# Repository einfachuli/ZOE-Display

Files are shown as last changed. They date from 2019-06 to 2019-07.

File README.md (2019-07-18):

# ZOE-Display

<pre>
!!!!!!!!!!!!!!!!!!!!!!!!!!!!!!!!!!!!!!!!!!!!!!!!!!!!!!!!!!!!!!!!!!
!!!! OHNE GEWÄHR, ALLES AUF EIGENE GEFAHR, NUR ZU TESTZWECKEN !!!!
!!!!!!!!!!!!!!!!!!!!!!!!!!!!!!!!!!!!!!!!!!!!!!!!!!!!!!!!!!!!!!!!!!
</pre>

## Verwendete Bauteile

- ESP32-Development-Board (z.B. https://www.ebay.de/itm/162572643462 oder https://www.amazon.de/gp/product/B071P98VTG)
- 2,8 Zoll 240 x 320 SPI TFT Panel resistiver Touchscreen (mit Display-Treiber ILI9341, z.B. https://www.amazon.de/gp/product/B0749N3S33/)
- alternativ mit kapazitivem Touchscreen (Adafruit 1947 mit Display-Treiber ILI9341, z.B. https://www.amazon.de/gp/product/B00R3R65C0/ oder https://www.mouser.de/ProductDetail/Adafruit/1947?qs=GURawfaeGuArmJSJoJoDJA%3D%3D)
- SD-Karte (bei resistivem Touchscreen) bzw. microSD-Karte (bei kapazitivem Touchscreen)
- optional GPS-Modul (z.B. https://www.ebay.de/itm/163636495985 oder https://www.amazon.de/gp/product/B01N38EMBF/)
- Kleinteile (siehe Ordner zur jeweiligen Platinen-Version)

## Verbindungen mit resistivem Touchscreen
<pre>
ESP32 Dev Board Pinout

Wohin           Bezeich.       ESP32 Pins       Bezeich.    Wohin

                            3V3         GND
                            EN          G23     MOSI        Display,Touch,SD
                ST          G36         G22
                            G39         G1      (TX)
                            G34         G3      (RX)
                (CAN2 RX)   G35         G21     CS          Touch
                (CAN2 TX)   G32         GND
                HR          G33         G19     MISO        Display,Touch,SD
                            G25         G18     SCLK        Display,Touch,SD
GPS             GPS TX      G26         G5 
GPS             GPS RX      G27         G17     CAN TX      CAN Bus
BUZZER+                     G14         G16     CAN RX      CAN Bus 
                POWER OFF   G12         G4      RST         Display
                            GND         G0      (BOOT)
SD              CS          G13         G2      DC          Display
                (Flash)     G9          G15     CS          Display
                (Flash)     G10         G8      (Flash)
                (Flash)     G11         G7      (Flash)
                            5V          G6      (Flash)
</pre>                    
RX und TX gibt den Pin an, mit dem es verbunden werden muss. GPS TX muss also auf den Pin
TX am GPS Modul! 

CAN2 ist derzeit experimentell. 

ST = Screen Turn, ST=1 (mit 10k auf 3V3) -> Bildschirm um 180 Grad gedreht

HR = Helligkeitsregelung, kann einen Transistor ansteuern, über den die LED-Hintergrundbeleuchtung des Displays gedimmt werden kann.

POWER OFF = Ausschalt-Pin für die Stromversorgung über den OBD-Port

## Verbindungen mit kapazitivem Touchscreen
<pre>
ESP32 Dev Board Pinout

Wohin           Bezeich.       ESP32 Pins       Bezeich.    Wohin

                            3V3         GND
                            EN          G23     SPI MOSI    Display
                ST          G36         G22     I²C SCL     Display
                            G39         G1      (TX)
                            G34         G3      (RX)
                (CAN2 RX)   G35         G21 
                (CAN2 TX)   G32         GND
Display         HR          G33         G19     SPI MISO    Display
Display         I²C SDA     G25         G18     SPI SCLK    Display
GPS             GPS TX      G26         G5
GPS             GPS RX      G27         G17     CAN TX      CAN Bus
BUZZER+                     G14         G16     CAN RX      CAN Bus 
                POWER OFF   G12         G4      RST         Display
                            GND         G0      (BOOT)
Display         CARDCS      G13         G2      DC          Display
                (Flash)     G9          G15     CS          Display
                (Flash)     G10         G8      (Flash)
                (Flash)     G11         G7      (Flash)
                            5V          G6      (Flash)
</pre>                    
RX und TX gibt den Pin an, mit dem es verbunden werden muss. GPS TX muss also auf den Pin
TX am GPS Modul! 

CAN2 ist derzeit experimentell. 

ST = Screen Turn, ST=1 (mit 10k auf 3V3) -> Bildschirm um 180 Grad gedreht

HR = Helligkeitsregelung, an Pin GPIO33 liegt ein PWM Signal an, welches über Pin D5 am Display
(neben CARDCS) die Regelung der Displayhelligkeit erlaubt. Achtung: Die Lötbrücke #5 auf der 
Displayplatine muss hierfür gesetzt werden.

POWER OFF = Ausschalt-Pin für die Stromversorgung über den OBD-Port
                    
## Allgemein
-  Beim Betrieb des resistiven Displays mit 3,3 V sollte der Jumper J1 am Display gesetzt (verbunden) werden (Ausschalten
des Spannungsreglers des Displays, sonst sinken die 3,3 V auf irgendwas unter 3 V). Der Touch IRQ Pin bleibt leer.
- Das Display mit kapazitivem Touchscreen erhält 5 V Versorgungsspannung. Falls das verwendete Display keine IOREF-Lötbrücke besitzt bzw. diese auf 5 V gesetzt wurde, muss eine geeignete Maßnahme vorgesehen werden, um die Spannungspegel am I²C-Bus auf max. 3,3 V zu begrenzen (das Display zieht die Leitungen nämlich mit 10-kΩ-Pull-Up-Widerständen gegen 5 V).

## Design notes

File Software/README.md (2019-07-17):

## Software

Anleitung von Erich (eokgnah)

<pre>
!!!!!!!!!!!!!!!!!!!!!!!!!!!!!!!!!!!!!!!!!!!!!!!!!!!!!!!!!!!!!!!!!!
!!!! OHNE GEWÄHR, ALLES AUF EIGENE GEFAHR, NUR ZU TESTZWECKEN !!!!
!!!!!!!!!!!!!!!!!!!!!!!!!!!!!!!!!!!!!!!!!!!!!!!!!!!!!!!!!!!!!!!!!!
</pre>

1. Holt euch die Arduino-IDE: 
https://www.arduino.cc/en/Main/Software

2. Macht die IDE nach Anleitung bereit für den ESP32: 
Testing ist dabei auszulassen. (ESP32 Version 1.0.2 im Boardmanager verwenden für SOFTWARE ab 2.112, sonst 1.0.1)
https://randomnerdtutorials.com/installing-the-esp32-board-in-arduino-ide-windows-instructions/

3. Kontrolliert die Einstellungen und installiert auf Eurem neuen ESP32 zum Initialisieren den „bare minimum“-Sketch aus den Beispielen (COM-Port kann bei Euch ggf. ein anderer sein).

Einstellungen der Arduino-IDE

Bare-Minimum-Sketch

Wenn das alles sauber durchgelaufen ist, dann geht es weiter.

4. Holt Euch die „Flash Download Tools (ESP8266 & ESP32)“ von espressif: 
https://www.espressif.com/en/support/download/other-tools

5. Holt Euch das ZOE-Display-Binary (oben in der Ordnerstruktur die entsprechende Datei auswählen oder direkt über den Link https://github.com/eokgnah/ZOE-Display/raw/master/Software/CAN-ESP32.ZOE.esp32-v2.075.bin).

6. Startet die „Flash Download Tools (ESP8266 & ESP32)“, wählt den ESP32 aus und stellt ihn wie folgt ein (COM-Port kann bei Euch ggf. ein anderer sein):

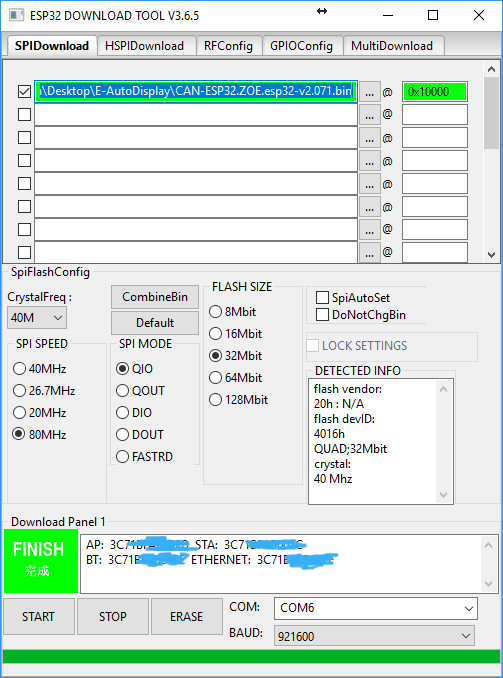
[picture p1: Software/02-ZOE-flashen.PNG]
Einstellungen des Flash Download Tools


7. Auf „START“ drücken und ihn flashen lassen.

8. Wenn er fertig ist, dann könnt Ihr beim ESP mal auf Reset drücken oder ihn kurz vom USB-Strom nehmen, damit er bootet.

9. Es sollte nun ein offener WLAN-Accesspoint (Name so etwas wie „ESP_12BA5C“ oder „ZOE“) bei Euch erschienen sein. 

10. Mit dem WLAN verbinden und auf die IP „192.168.4.1“ mit dem Browser gehen und dann könnt Ihr alles von dort aus über den Browser weiter konfigurieren.

Das alles geht auch nur mit dem ESP32 alleine.
Damit es „sinnvoll“ funktioniert ist es natürlich von Vorteil, wenn Ihr das Display, die SD-Karte, GPS und das CAN-Interface mit anschließt.  

Neuere Updates kommen dann per WLAN „over the air“.
Diese beschriebene Vorgehensweise ist nur ein einziges Mal am Anfang nötig. Danach braucht Ihr keinen PC mehr.

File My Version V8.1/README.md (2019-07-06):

# Platine und kap. Einleger V8.1

von einfachuli (ZOE-Aachen)

<pre>

!!!!!!!!!!!!!!!!!!!!!!!!!!!!!!!!!!!!!!!!!!!!!!!!!!!!!!!!!!!!!!!!!!
!!!! OHNE GEWÄHR, ALLES AUF EIGENE GEFAHR, NUR ZU TESTZWECKEN !!!!
!!!! Das Projekt ist für Messe- und Laborzwecke bestimmt      !!!!
!!!!!und für die Verwendung im Bereich der StVO nicht zugelassen!!
!!!!!!!!!!!!!!!!!!!!!!!!!!!!!!!!!!!!!!!!!!!!!!!!!!!!!!!!!!!!!!!!!!

</pre>

##  Versionshinweise V8.1

- kap. Display nur mit ioref 3V unterstützt ! keine PullDowns R4 und R7 am I2C Bus, da ich nur Displays mit ioref verwende 

- statt Lötbrücke SJ2 für die 5V Stromversorgung kap. Display über ESP USB Anschluss, Kodierbrücke bei Bedarf auf Jumper steckbar

- ich verwende Sockelleisten um den ESP und ggf auch das GPS zu sockeln. Sockelleisten sind dabei nur 5,7 mm hoch.

- kapazitive Display wird direkt auf die Pinabstandsleiste des Displays gelötet und sitzt damit 1,6 mm tiefer im Einleger. 
   --> Dazu mussen die Lötstellen auf der Platine sauber geschnitten werden.

- ggf. Reset- bzw. Ein-Aus-Schalter, als Unterbrecher vor der 12V+ Klemme.

- resistives Display und Spannungsregler U2 Version OKI-78SR-5/1.5-W36-C ist von der Höhe ungünstig, wenn es in die Mulde passen soll.      Besser ist hier eine niedrigere Bauform, wie z.B. bei Gaptec LMP78_05-1.5 DC/DC-Wandler

## Bilddoku: 
  siehe https://github.com/einfachuli/ZOE-Display/tree/master/My%20Version%20V8.1/Bilder

## alles Weitere steht in der Bauanleitung Version Platine V8. 
  siehe https://github.com/einfachuli/ZOE-Display/blob/master/Platine%20V8/README.md

## Bezugsquellen zusätzlich verwendete Bauteile:

  - Codierbrücke: https://www.conrad.de/de/p/codierbruecke-cab-pole-2-cab-9-g-r-fischer-elektronik-736318.html

  - niedrige Sockelleisten: https://www.reichelt.de/buchsenleiste-36-polig-vergoldet-2-54-bkl-10120802-p235673.html?

  - U2 Version flach: https://www.conrad.de/de/p/gaptec-lmp78-05-1-5-dc-dc-wandler-print-24-v-dc-5-v-dc-1500-ma-7-5-w-anzahl-ausgaenge-1-x-1603649.html

  - Reset Drucktaster: https://www.conrad.de/de/p/sci-r13-502b-05rt-drucktaster-250-v-ac-1-5-a-1-x-ein-aus-tastend-1-st-701100.html

  - 3D Drucke: https://www.s3dproducts.de/

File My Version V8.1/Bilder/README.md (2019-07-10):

## Bilder

### Einleger PETG mit Carbonanteil

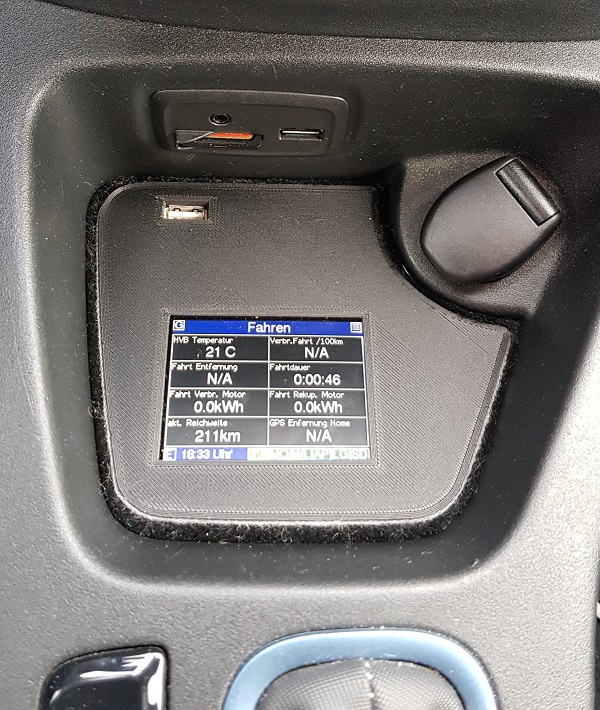
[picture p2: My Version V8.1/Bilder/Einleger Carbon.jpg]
Einleger PETG mit Carbonanteil


### Grau 12V Stromunterbrecher für Reset

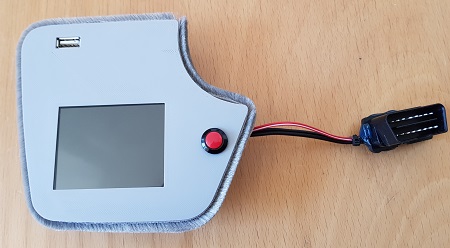
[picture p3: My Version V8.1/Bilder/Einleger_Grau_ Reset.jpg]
Einleger_Grau_ Reset


### Zoe Display V8.1

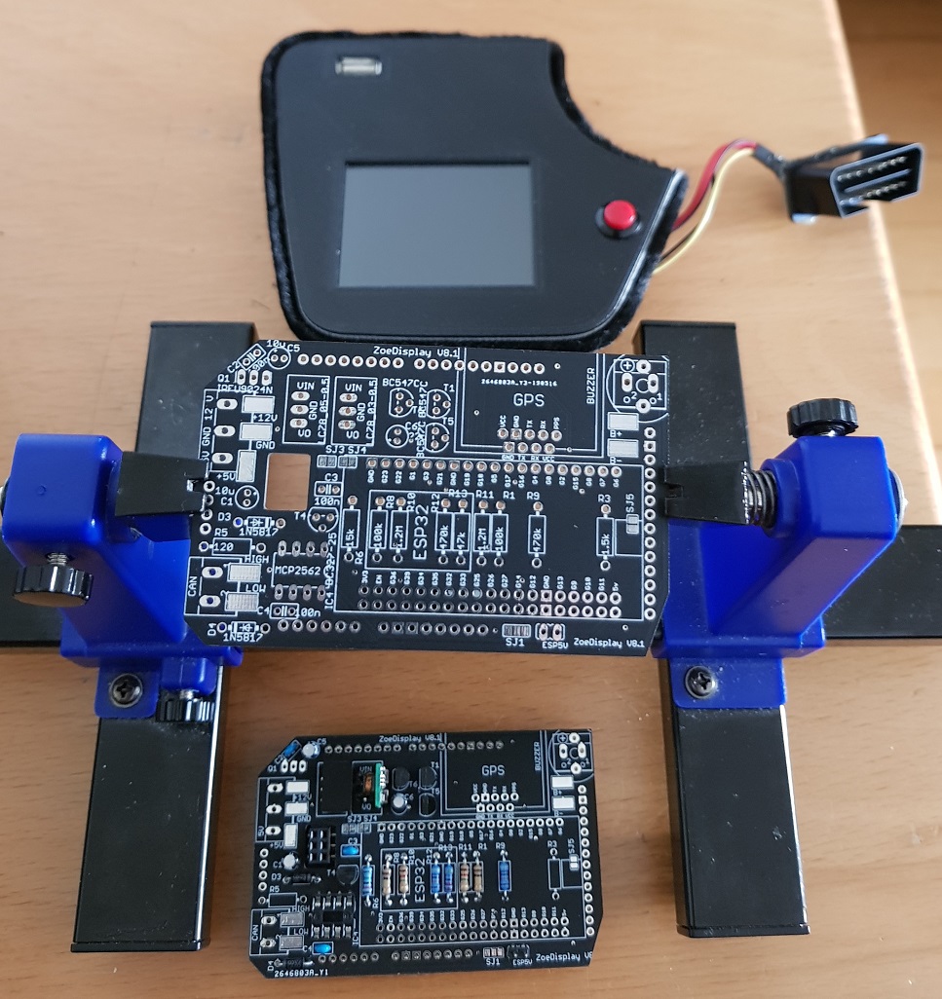
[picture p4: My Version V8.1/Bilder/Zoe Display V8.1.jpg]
Zoe Display V8.1


### Zoe Display Rückseite

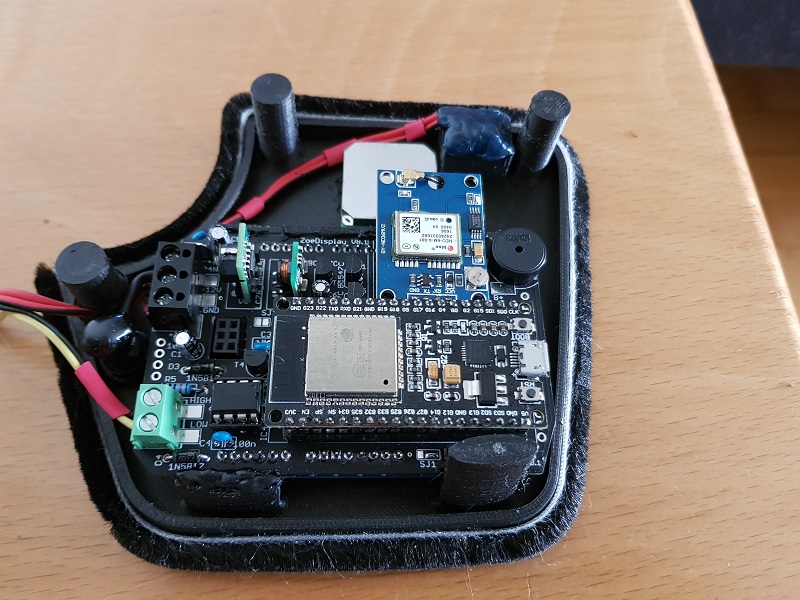
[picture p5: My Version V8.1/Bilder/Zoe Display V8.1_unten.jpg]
Zoe Display V8.1_unten


### Einleger Grau Reset Rückseite

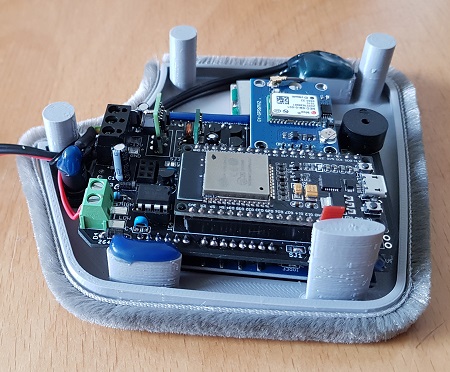
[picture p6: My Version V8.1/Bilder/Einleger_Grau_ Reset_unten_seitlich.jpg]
Einleger_Grau_ Reset_unten_seitlich


### Display resistiv zerlegbar

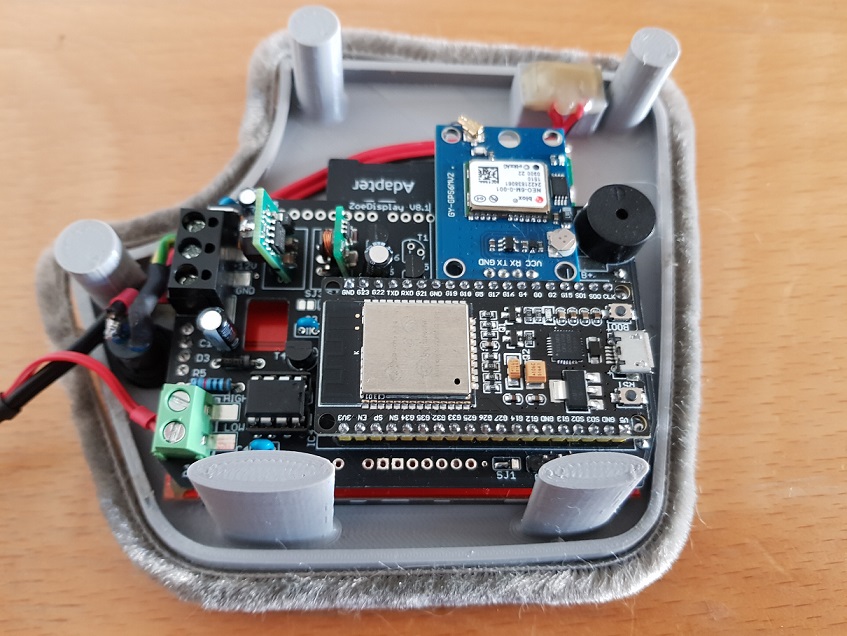
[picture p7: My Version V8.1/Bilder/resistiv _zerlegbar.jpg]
resistiv _zerlegbar


### Display resistiv zerlegbar Schritt 1

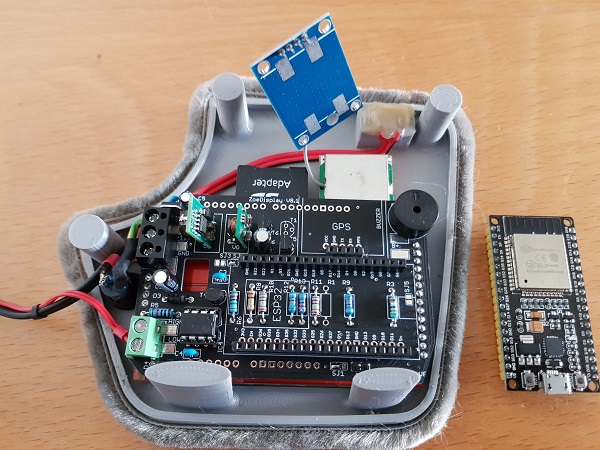
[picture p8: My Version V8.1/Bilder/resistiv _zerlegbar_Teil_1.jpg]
resistiv _zerlegbar_Teil_1


### Display resistiv zerlegbar Schritt 2

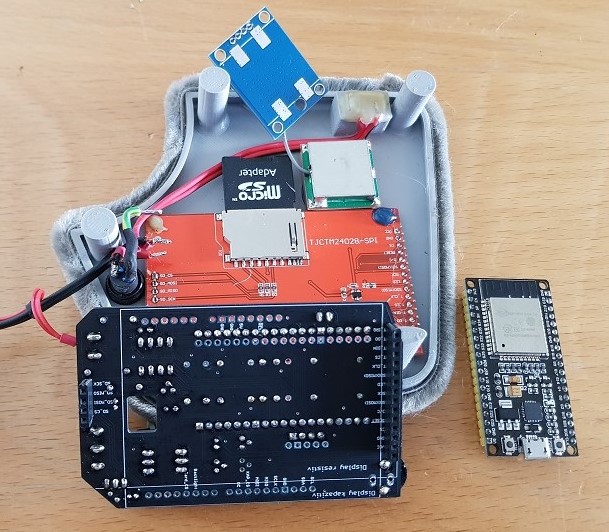
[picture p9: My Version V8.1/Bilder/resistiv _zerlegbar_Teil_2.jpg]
resistiv _zerlegbar_Teil_2


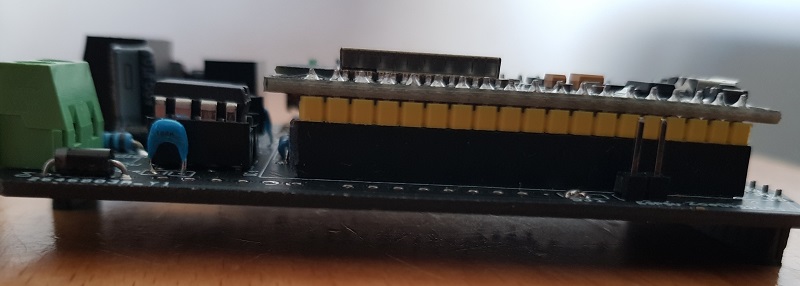
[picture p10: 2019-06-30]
My Version V8.1/Bilder/resistiv_zerlegbar_seitenansicht.jpg

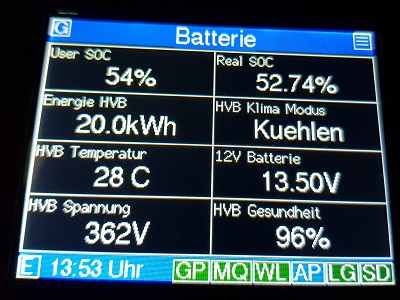
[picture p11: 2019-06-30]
My Version V8.1/Bilder/Bildschirme/05 Batterie.jpg

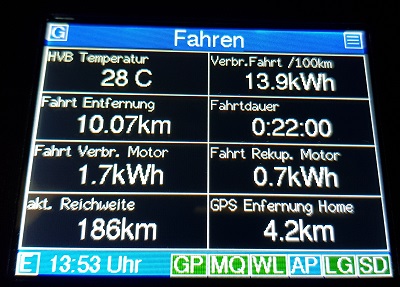
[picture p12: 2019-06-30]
My Version V8.1/Bilder/Bildschirme/03 Fahren.jpg

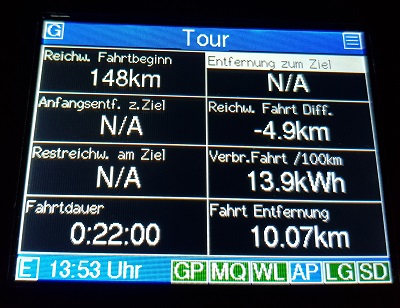
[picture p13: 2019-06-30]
My Version V8.1/Bilder/Bildschirme/04 Tour.jpg

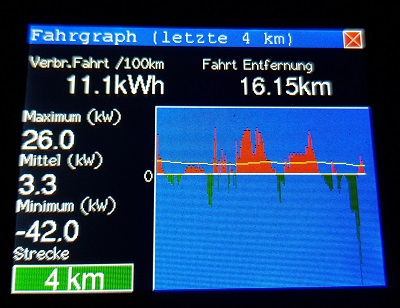
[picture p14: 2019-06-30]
My Version V8.1/Bilder/Bildschirme/10 Fahrgrafik.jpg

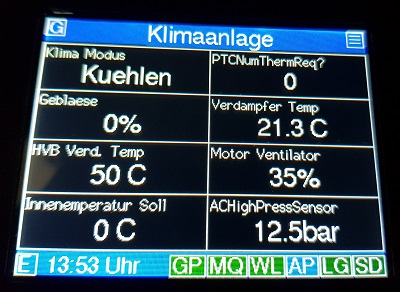
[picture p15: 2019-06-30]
My Version V8.1/Bilder/Bildschirme/06 Klimaanlage.jpg

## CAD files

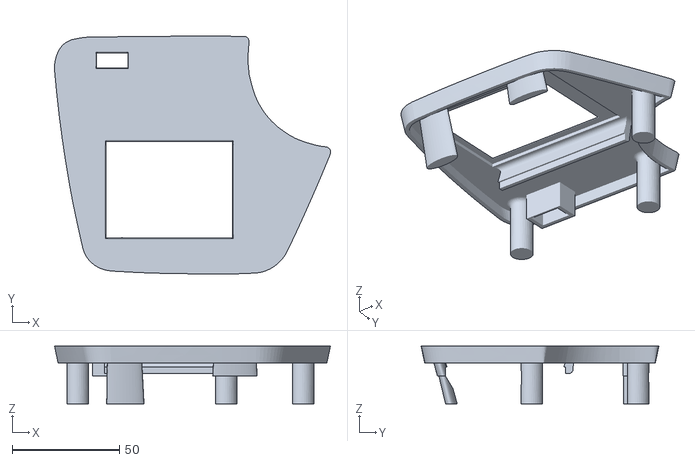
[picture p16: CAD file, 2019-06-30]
My Version V8.1/Zoe-Einleger-Kapa-V8.1.stl
128.6 x 110.8 x 27.0

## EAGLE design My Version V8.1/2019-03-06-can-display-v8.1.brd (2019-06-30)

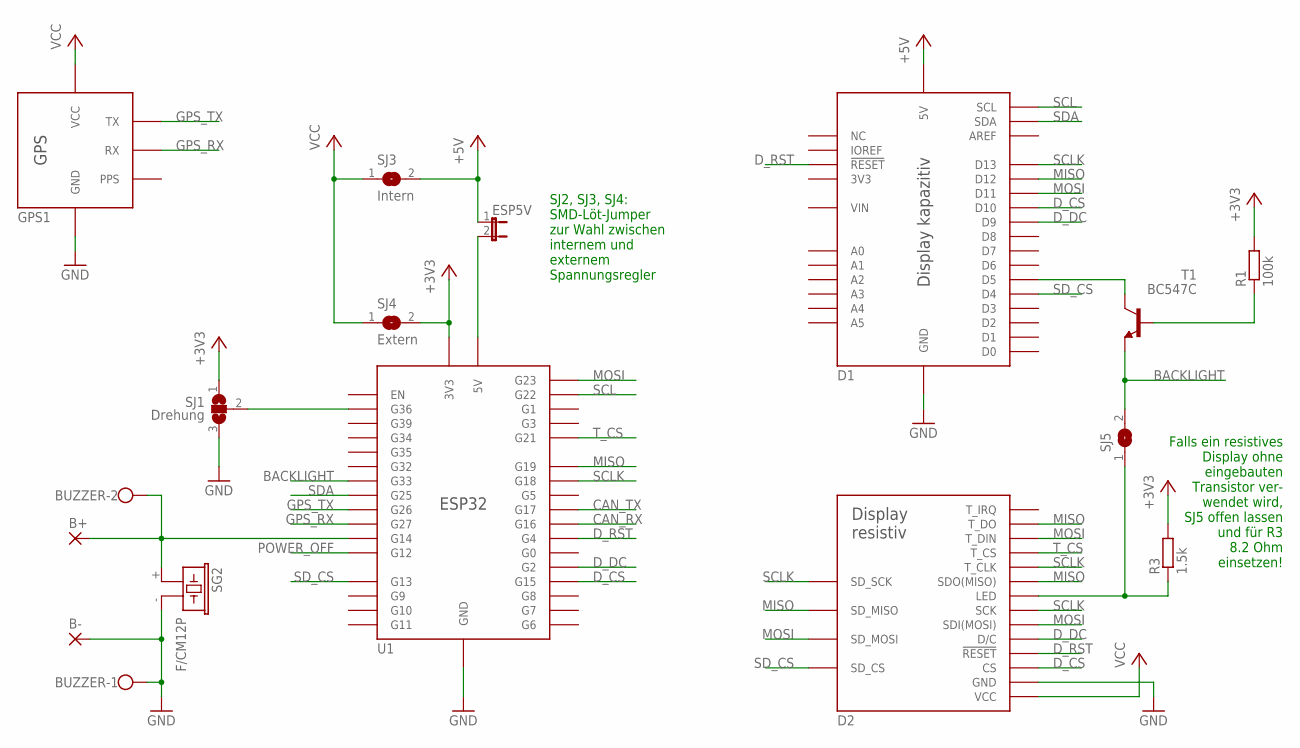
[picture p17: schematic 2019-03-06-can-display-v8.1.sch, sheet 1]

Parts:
B+: WIREPADSMD5-2,5; 5-2,5
B-: WIREPADSMD5-2,5; 5-2,5
BUZZER: W237-102
D1: TFT-KAPAZITIV
D2: TFT-RESISTIV
ESP5V: ESP 5V; JP1
GPS1: GPS
R1: 100k; VMTA55
R3: 1.5k; VMTA55
SG2: F/CM12P
SJ1: Drehung; SJ_2
SJ3: Intern; SJ
SJ4: Extern; SJ
SJ5: const.; SJ
T1: BC547C; TO92
U1: ESP32

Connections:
+3V3: R1.2, R3.2, SJ1.1, SJ4.2, U1.3V3, U1.3V3S (3V3); also elsewhere on the board
+5V: D1.5V, ESP5V.1, SJ3.2; also elsewhere on the board
BACKLIGHT: SJ5.2, T1.1 (E), U1.G33, U1.G33S (G33)
BUZZER: B+.1, BUZZER.2, SG2.+ (1), U1.G14, U1.G14S (G14)
CAN_RX: U1.G16; also elsewhere on the board
CAN_TX: U1.G17; also elsewhere on the board
DIS-BL: D2.LED, R3.1, SJ5.1
D_CS: D1.D10, D2.LCD_CS (CS), U1.G15
D_DC: D1.D9, D2.LCD_DC (D/C), U1.G2
D_RST: D1.RESET (!RESET!), D2.LCD_RESET (!RESET!), U1.G4
ESP5V: ESP5V.2, U1.5V, U1.5VS (5V)
GND: B-.1, BUZZER.1, D1.GND@1 (GND), D1.GND@2 (GND), D1.GND@3 (GND), D2.GND, GPS1.GND1 (GND), GPS1.GND2 (GND), SG2.- (2), SJ1.3, U1.GND@1 (GND), U1.GND@2 (GND), U1.GND@3 (GND), U1.GND@4 (GND); also elsewhere on the board
GPS_RX: GPS1.RX1 (RX), GPS1.RX2 (RX), U1.G27, U1.G27S (G27)
GPS_TX: GPS1.TX1 (TX), GPS1.TX2 (TX), U1.G26, U1.G26S (G26)
MISO: D1.D12, D2.LCD_MISO (SDO(MISO)), D2.SD_MISO, D2.T_DO, U1.G19
MOSI: D1.D11, D2.LCD_MOSI (SDI(MOSI)), D2.SD_MOSI, D2.T_DIN, U1.G23
unnamed: SJ1.2, U1.G36, U1.G36S (G36)
unnamed: D1.D5, T1.3 (C)
unnamed: R1.1, T1.2 (B)
POWER_OFF: U1.G12, U1.G12S (G12); also elsewhere on the board
SCL: D1.KAP_SCL (SCL), U1.G22
SCLK: D1.D13, D2.LCD_SCK (SCK), D2.SD_SCK, D2.T_CLK, U1.G18
SDA: D1.KAP_SDA (SDA), U1.G25, U1.G25S (G25)
SD_CS: D1.D4, D2.SD_CS, U1.G13, U1.G13S (G13)
T_CS: D2.T_CS, U1.G21
VCC: D2.VCC, GPS1.VCC1 (VCC), GPS1.VCC2 (VCC), SJ3.1, SJ4.1; also elsewhere on the board

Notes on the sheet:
SJ2, SJ3, SJ4: SMD-Löt-Jumper zur Wahl zwischen internem und externem Spannungsregler
Falls ein resistives Display ohne eingebauten Transistor ver- wendet wird, SJ5 offen lassen und für R3 8.2 Ohm einsetzen!

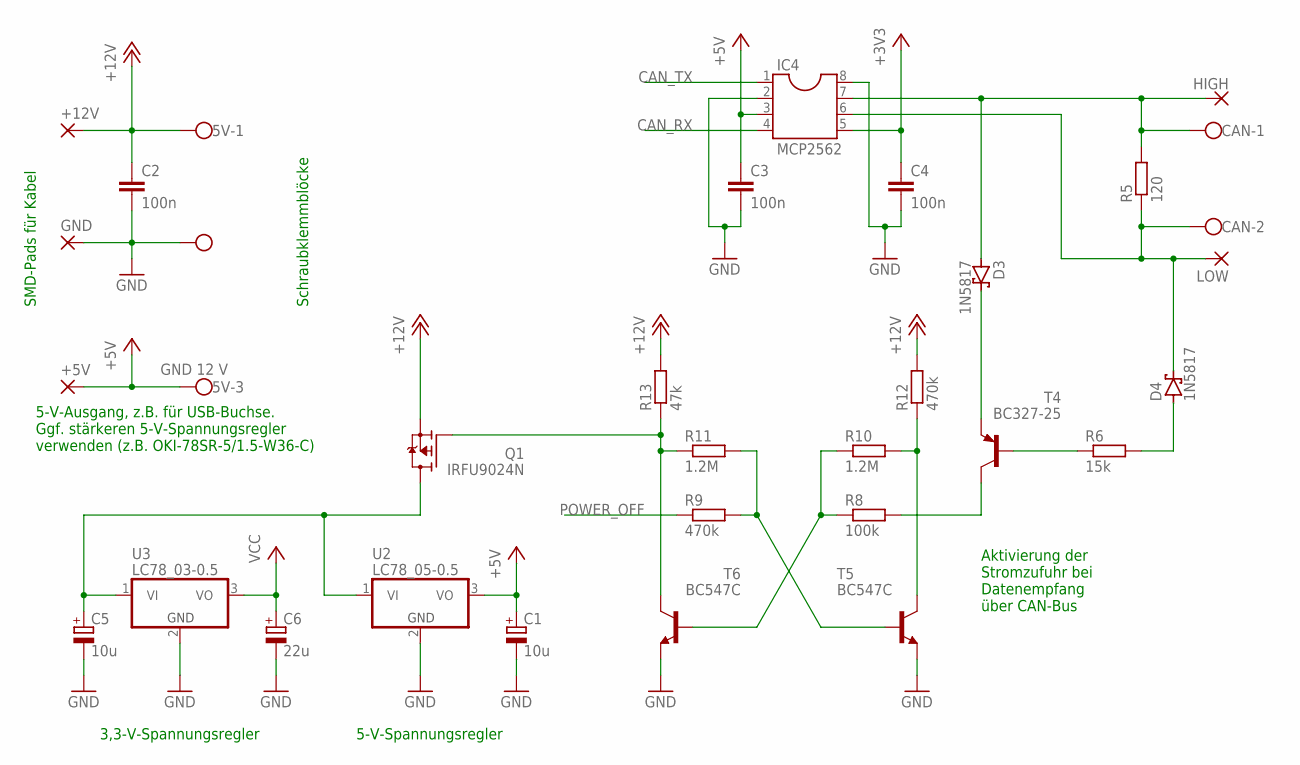
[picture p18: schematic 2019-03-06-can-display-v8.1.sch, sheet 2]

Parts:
5V: GND 12 V; W237-103
+5V, +12V: WIREPADSMD5-2,5; 5-2,5
C1, C5: 10u; E1,8-4
C2, C3, C4: 100n; C025-025X050
C6: 22u; E1,8-4
CAN: W237-102
D3, D4: 1N5817; DO41-7.6
GND: WIREPADSMD5-2,5; 5-2,5
HIGH: WIREPADSMD5-2,5; 5-2,5
IC4: MCP2562; DIL08
LOW: WIREPADSMD5-2,5; 5-2,5
Q1: IRFU9024N; TO251AA-V
R5: 120; VMTA55
R6: 15k; VMTA55
R8: 100k; VMTA55
R9, R12: 470k; VMTA55
R10, R11: 1.2M; VMTA55
R13: 47k; VMTA55
T4: BC327-25; TO92
T5, T6: BC547C; TO92
U2: LC78_05-0.5; SPANNUNGSREGLER
U3: LC78_03-0.5; SPANNUNGSREGLER

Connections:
+3V3: C4.1, IC4.5; also elsewhere on the board
+5V: 5V.3, +5V.1, C1.+, C3.1, IC4.3, U2.3 (VO); also elsewhere on the board
+12V: 5V.1, +12V.1, C2.1, Q1.3 (S), R12.2, R13.2
CAN_RX: IC4.4; also elsewhere on the board
CAN_TX: IC4.1; also elsewhere on the board
GND: 5V.2, C1.-, C2.2, C3.2, C4.2, C5.-, C6.-, GND.1, IC4.2, IC4.8, T5.1 (E), T6.1 (E), U2.2 (GND), U3.2 (GND); also elsewhere on the board
unnamed: D3.C, T4.1 (E)
unnamed: R6.1, T4.2 (B)
unnamed: D4.A, R6.2
unnamed: R8.1, R10.1, T6.2 (B)
unnamed: CAN.1, D3.A, HIGH.1, IC4.7, R5.2
unnamed: CAN.2, D4.C, IC4.6, LOW.1, R5.1
unnamed: R8.2, T4.3 (C)
unnamed: R9.2, R11.2, T5.2 (B)
unnamed: R10.2, R12.1, T5.3 (C)
unnamed: Q1.1 (G), R11.1, R13.1, T6.3 (C)
unnamed: C5.+, Q1.2 (D), U2.1 (VI), U3.1 (VI)
POWER_OFF: R9.1; also elsewhere on the board
VCC: C6.+, U3.3 (VO); also elsewhere on the board

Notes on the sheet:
3,3-V-Spannungsregler
5-V-Spannungsregler
Aktivierung der Stromzufuhr bei Datenempfang über CAN-Bus
SMD-Pads für Kabel
Schraubklemmblöcke
5-V-Ausgang, z.B. für USB-Buchse. Ggf. stärkeren 5-V-Spannungsregler verwenden (z.B. OKI-78SR-5/1.5-W36-C)

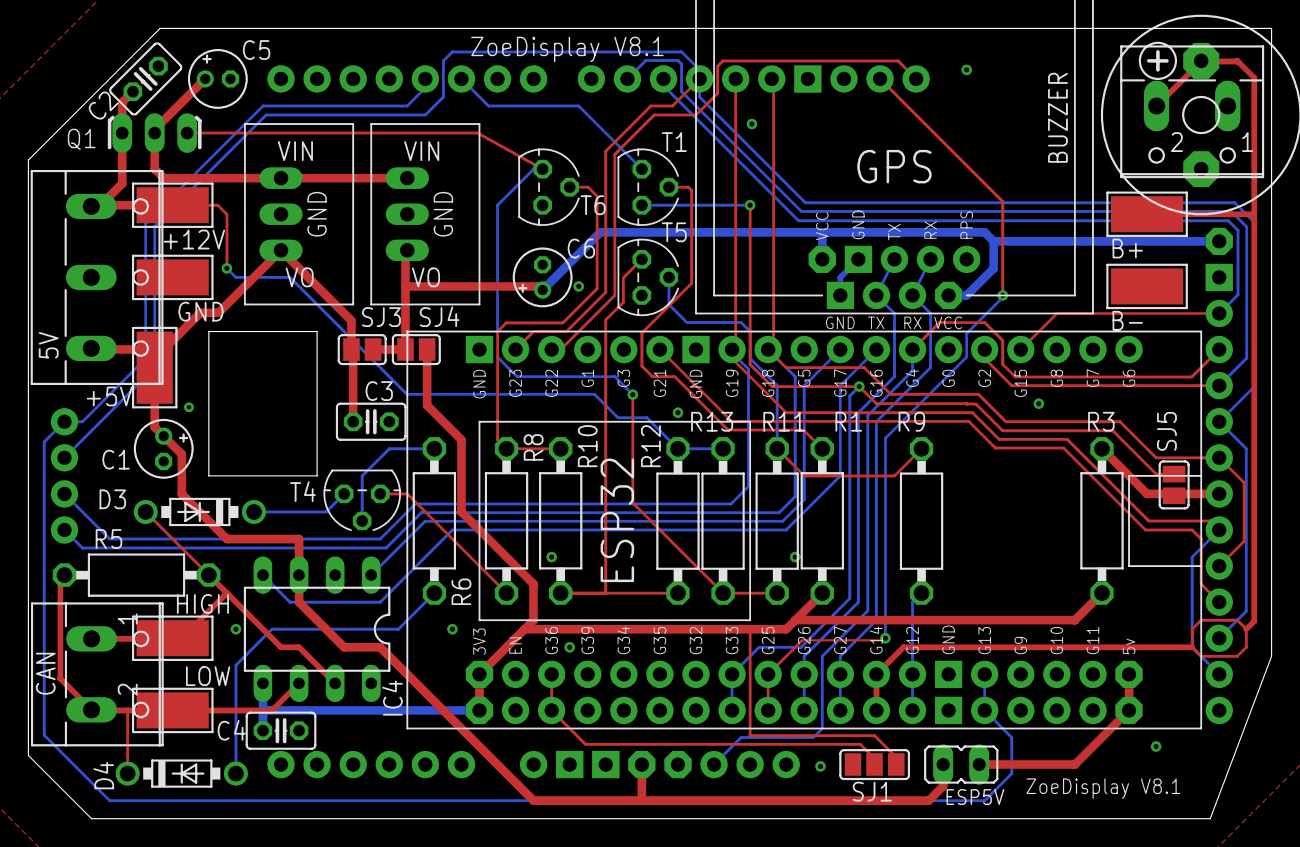
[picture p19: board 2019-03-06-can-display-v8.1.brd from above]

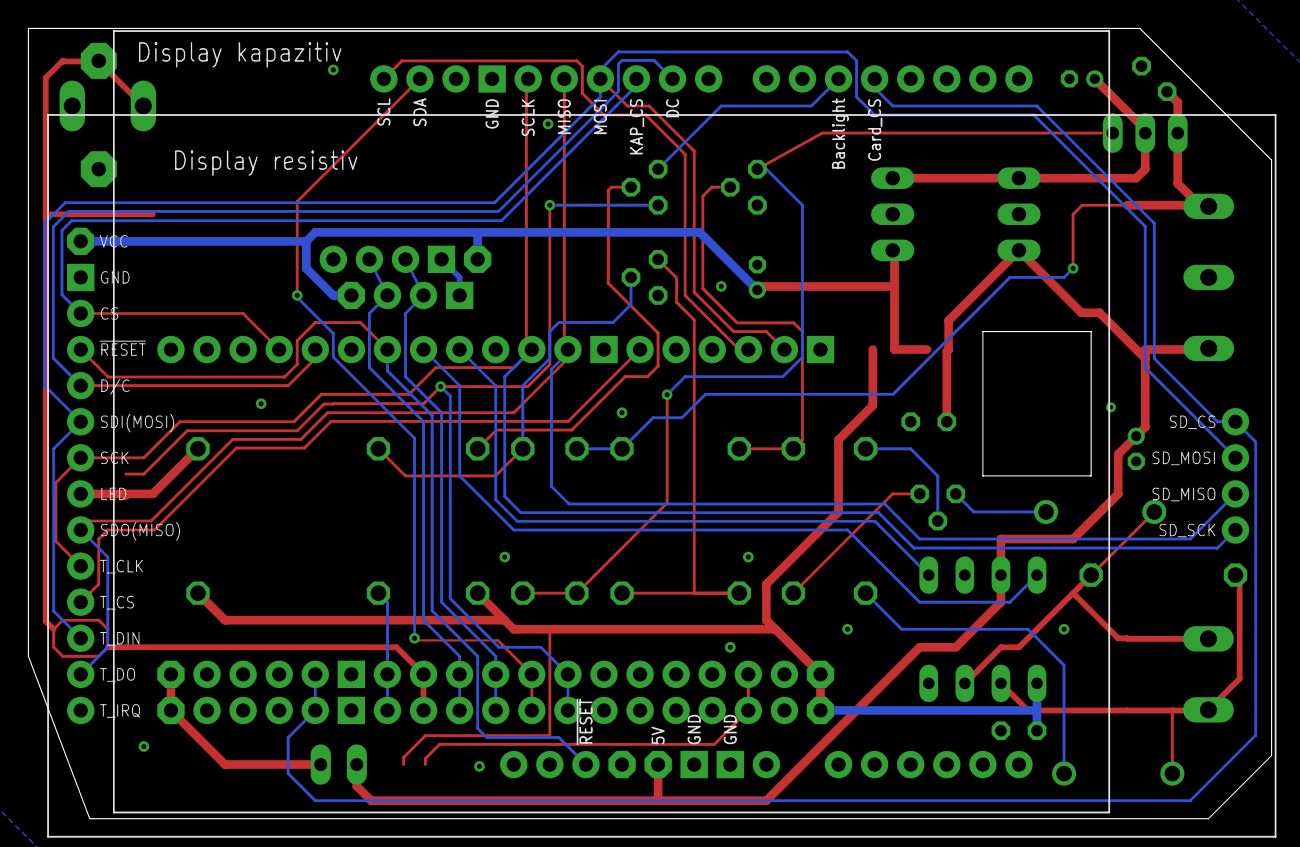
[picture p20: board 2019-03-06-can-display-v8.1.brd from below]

Board: 2 copper layers, 87.5 x 55.6 mm, 46 parts (2 on the bottom side), 38 nets.

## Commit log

2019-06-30 Eagle Files meiner Platinenversion
    Jumper für SJ2 5V von ESP eingefügt. Kann jetzt bei Bedarf gesetzt werden.
    C2 versetzt. Transitoren neu ausgerichtet. R4 und R7 entfernt, alle Displays hatten ioref. kleine Änderungen der Traces.
    [2019-03-06-can-display-v8.1.brd, 2019-03-06-can-display-v8.1.sch]
2019-06-30 Kapazitiven Einleger angepasst
    Platinenauflage um 1,6 mm tiefergelegt. Damit kann die Planine näher an das Display gesetzt werden. Alles wird etwas weniger hoch.
    [Zoe-Einleger-Kapa-V8.1.stl]
2019-06-30 meine Version 8.1 black Edition mit Reset
    ESP ist gesockelt, Reset unterbricht die 12V+, Einleger ist in PETG mit Carbonanteil gedruckt.
2019-06-30 meine Version 8.1 grau mit Reset
    ESP ist gesockelt, Reset unterbricht die 12V+, Einleger ist in PETG gedruckt.
2019-06-30 resistves Display gesockelt, zerlegbar
    ESP, GPS und Platine-Display Verbingung sind gesockelt.
2019-06-30 SPI Flash speed angepasst
    40MHz->80MHz
2019-06-30 Lizenzfile von der Display Software kopiert
2019-07-10 Delete CAN-ESP32.ZOE.esp32-v2.072.bin
    old Software deleted
2019-07-10 Create CAN-ESP32.ZOE.esp32-v2.087.bin
    Software with ESP Framework 1.0.1
2019-07-10 Create CAN-ESP32.ZOE.esp32-v2.112.bin
    Software with ESP Framwork 1.0.2
